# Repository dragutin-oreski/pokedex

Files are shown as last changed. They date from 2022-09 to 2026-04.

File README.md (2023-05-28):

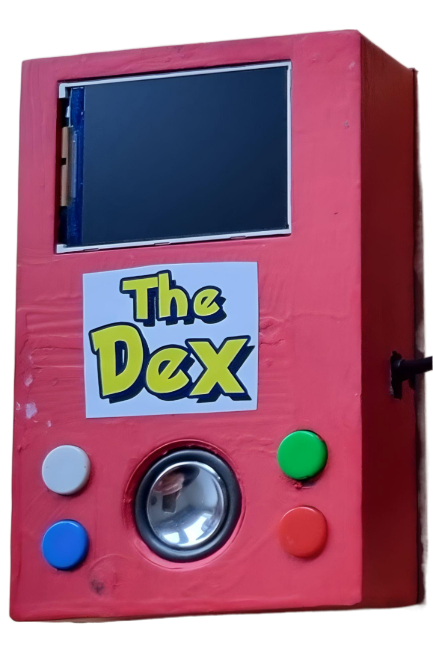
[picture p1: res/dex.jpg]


# Pokedex

The goal of the project was to create a device which can recognise objects and give information about them. 
It is powered by an external battery, and it can be carried around. It only detects objects when 
instructed to do it (when a button is pressed). 
It keeps a browseable history of all detected objects
<!--- The goal of the project is to create a device which can recognise objects and give you information about them.
It is powered by an external battery and you can carry it around.
It only detects objects when you instruct it to do it (when you press a button).
It keeps a history of all detected objects through which you can browse. --->

## Hardware
- [Raspberry Pi4 Model B 4GB](https://www.hgspot.hr/elektronicki-set-raspberry-pi-4-model-b-8gb-original-starter-kit-8gb-komplet)
- [LCD display 2.4 inch](https://www.amazon.de/-/en/Coolwell-Waveshare-General-Resolution-Embedded/dp/B08JCFC69B)
- [Speaker](http://www.elmatis.hr/ProductDetails.aspx?productId=52232)
- [Raspberry Pi camera 8MP V2](https://www.tme.eu/hr/en/details/rpi-camera-v2/accessories-for-embedded-systems/raspberry-pi/raspberry-pi-camera-8mp-v2/)
- [Amplifier](https://hr.mouser.com/ProductDetail/Adafruit/3006?qs=SV%252B0z0o3NTtodS8r%2Ftqo5A%3D%3D)

## Software
This repository contains code which should be run on the device.
Device needs to have OS set up.
I'd suggest following tutorials from [Q-engineering](https://github.com/Qengineering) for either installing an [OS with preinstalled OpenCV](https://github.com/Qengineering/Install-OpenCV-Raspberry-Pi-64-bits) or simply using their [wheels](https://github.com/Qengineering/Paddle-Raspberry-Pi).

## 3D print
In the repository, there is also a directory with .stl files for 3D printing.
An improvement would be to colour it to red immediately and to make the cylinders wider

## Acknowledgment

Special thanks to [Sam Makes](https://www.youtube.com/@sammakes3512) (especially his [video](https://www.youtube.com/watch?v=fbpM0oHZSb4)) and [Ivan Kunovic](https://www.linkedin.com/in/ivankunovic/) - I wouldn't have made it without you.

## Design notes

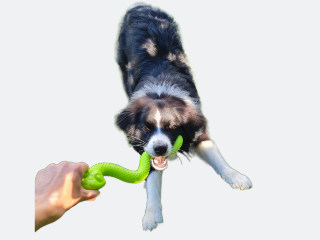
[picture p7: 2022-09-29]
res/classified/dex_entries/images/dog.jpg

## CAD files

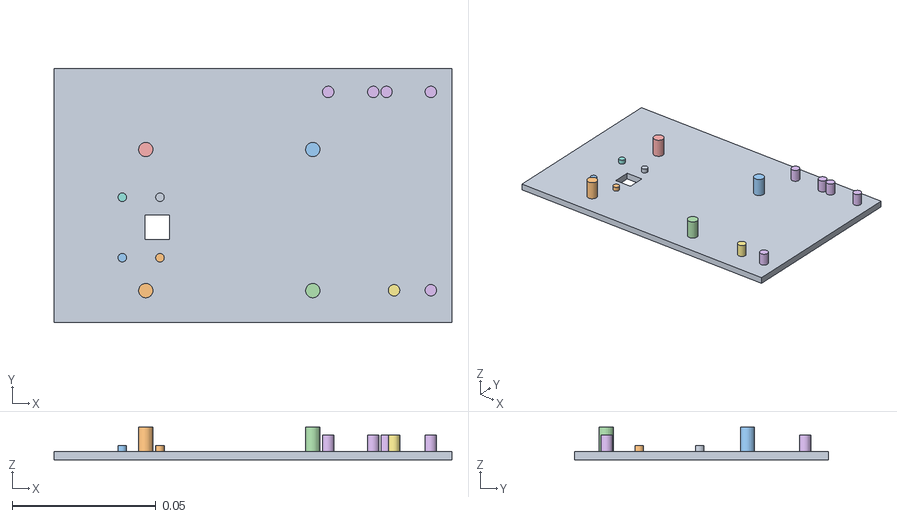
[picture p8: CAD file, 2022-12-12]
3d_print_models/rpi-pokedex-bottom-3dprint.stl
0.138 x 0.0882 x 0.0114
3DGeom-1
3DGeom-2 x 4
3DGeom-6
3DGeom-7
3DGeom-8 x 4

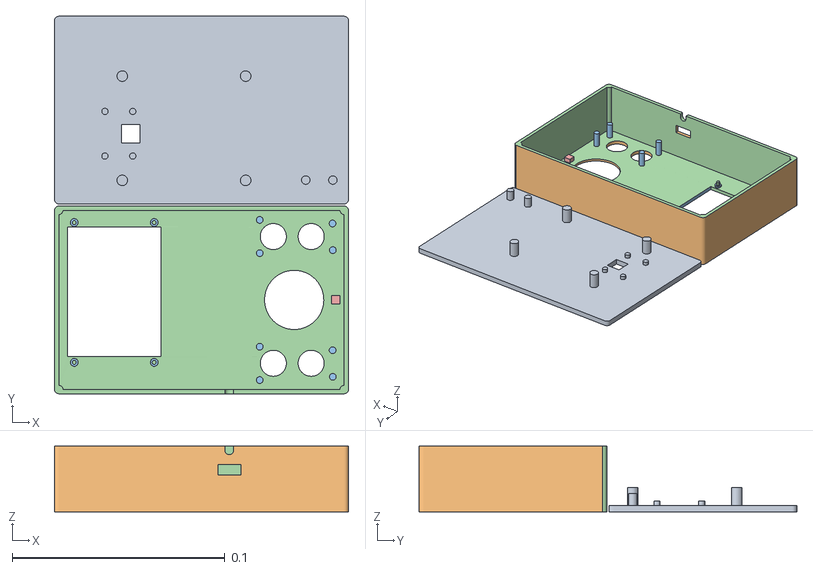
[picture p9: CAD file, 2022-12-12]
3d_print_models/rpi-pokedex-top-3dprint.stl
0.138 x 0.177 x 0.0308
3DGeom-1
3DGeom-2
3DGeom-3
3DGeom-4
3DGeom-5

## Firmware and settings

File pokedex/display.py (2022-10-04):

import time

from pokedex.resources import get_image_from_dex, get_background_image
from pokedex.services.lcd.lib.LCD_2inch4 import LCD_2inch4
import spidev as SPI
from PIL import Image


RST = 27
DC = 25
BL = 6
bus = 0
device = 0


def show_image(path):
    disp = _get_display()
    
    image = Image.open(path)
    image = image.rotate(180)
    image = image.resize((320, 240))
    
    disp.ShowImage(image)
    time.sleep(0.1)
    disp.module_exit()


def show_background():
    disp = _get_display()

    image = Image.open(get_background_image())
    image = image.rotate(180)
    disp.ShowImage(image)
    time.sleep(0.1)
    disp.module_exit()


def show_dex_image(found_class):
    image = Image.open(get_image_from_dex(found_class))
    image = image.rotate(180)
    
    disp = _get_display()
    disp.ShowImage(image)
    time.sleep(0.1)
    disp.module_exit()


def _get_display():
    """
    Get display ready
    """
    disp = LCD_2inch4(spi=SPI.SpiDev(bus, device), spi_freq=10000000, rst=RST, dc=DC, bl=BL)
    disp.Init()
    disp.clear()
    return disp

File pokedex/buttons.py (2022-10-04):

from gpiozero import Button

from pokedex.display import show_dex_image
from pokedex.resources import get_seen_names
from pokedex.sound import text_to_speech

button1 = Button(22)
button2 = Button(23)
button3 = Button(24)
button4 = Button(16)


def browse_seen():
    seen_names = get_seen_names()
    size = len(seen_names)
    index = 0

    if size > 0:
        show_dex_image(seen_names[index])

    while size > 0:

        if button2.is_pressed:
            index = (index + 1) % size
            show_dex_image(seen_names[index])

        if button3.is_pressed:
            text_to_speech(seen_names[index])
#             index = (index - 1) % size
#             show_dex_image(seen_names[index])

        if button4.is_pressed:
            text_to_speech(seen_names[index])

        if button1.is_pressed:
            return

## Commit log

2022-09-17 fix: update button layout
    [buttons.py]
2022-09-17 fix: make resources can load files dinamically, regardless of the folder in which they are
    [resources.py]
2022-09-17 fix: rename functions from resources in classifier
    [classifier.py]
2022-09-17 refactor: move delete_seen to buttons and use the right path to the folder
2022-09-18 fix: add the correct gstreamer pipeline
    [classifier.py]
2022-09-19 fix: use correct path to dex_entries/descriptions
    [resources.py]
2022-09-20 fix: reorganize switch4 into browse seen and generalize used functions
    [buttons.py, display.py, resources.py]
2022-09-20 fix: use full paths to scripts for running programs
    [resources.py]
2022-09-27 fix: extract running functions so that they work with buttons
2022-09-28 feat: add button4 to gpio 16
2022-09-29 feat: complete the buttons section with button4 which reads the text
2022-09-29 fix: rotate image on display
    [display.py]
2022-09-29 fix: remove unused show_dex_image_if_not_already_shown
    [buttons.py]
2022-09-29 fix: remove unused resource paths
    [resources.py]
2022-10-04 fix: override button4 which does not work properly any more (after problems with soldering
2022-10-04 fix: complete overriding non-working button4 with button3
    [buttons.py]
2022-10-04 fix: resize classification_image before displaying
    [display.py]
2026-04-26 Add unified Pokedex landing page
2026-04-27 Show device photo on Pokedex page
